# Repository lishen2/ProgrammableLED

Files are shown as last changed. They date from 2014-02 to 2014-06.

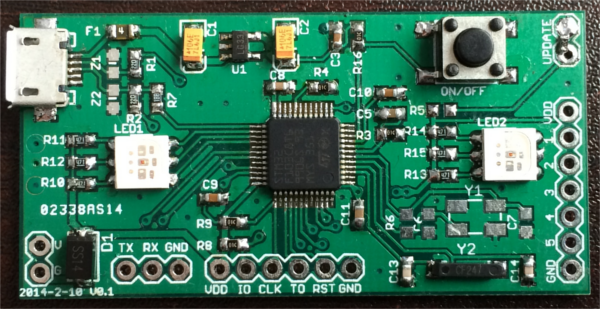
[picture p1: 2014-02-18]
images/IMG_0546.png

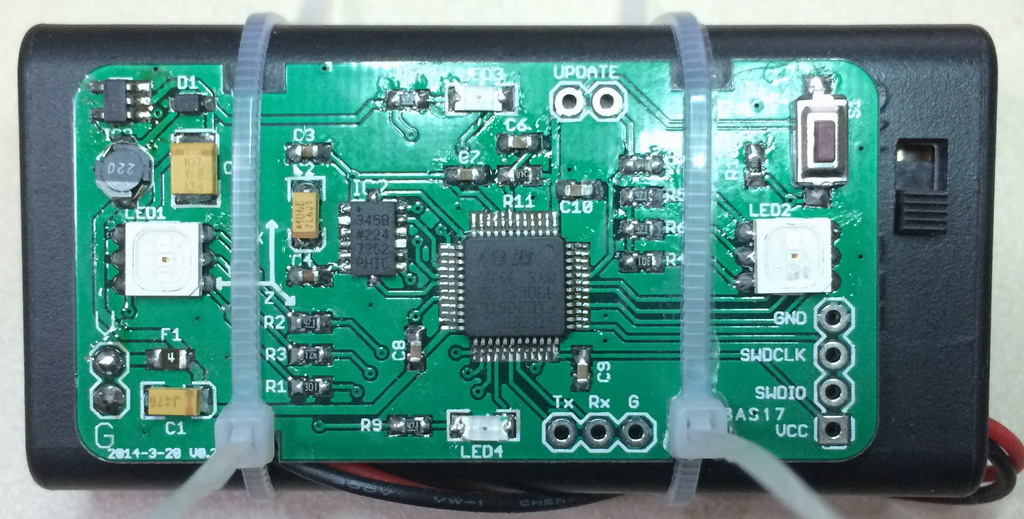
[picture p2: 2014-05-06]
images/finished2.JPG

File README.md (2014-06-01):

自动刹车灯
===============
自动刹车灯是一个小巧的电路板，在刹车减速时自动亮起。可以将其安装在自行车上，用于警示其他车辆和行人。自动刹车灯由电池供电并内置加速度传感器，因此无需额外连接其他线缆。使用两节5号电池时，设计待机时间为一年以上(待机功耗66微安)，基本可以实现永不关机，即装即忘。项目命名为“ProgrammableLED”是最初的初衷，现在已经简化为自动刹车等了，功能简化体验更优。


特性
--------
* 体积2.8cm * 5.5cm(PCB尺寸)。
* 自动识别减速刹车。
* 停车自动休眠，设计待机时间一年以上。
* 软硬件设计开源。

应用
-------
* 自行车灯，提高车辆夜间识别度，增强安全性。

硬件资源
--------
* STM32F103C8T处理器
* 两个全彩LED灯，两个红色LED（1206）
* 加速度传感器ADXL345
* 一个三线串口
* 一个三线SWD接口

当前进度
--------
20140217: 第一版PCB制作完成.                     
20140220: 编写代码，STM32的USB驱动示例代码很烂，作为程序员不忍直视。              
20140319: 放弃使用USB口，原因是USB驱动比较复杂一直没有调试成功。                  
20140329: 第二版PCB制作完成，放弃USB接口，增加加速度传感器ADXL234和升压电路（保证LED亮度一致）                    
20140410：还在编写软件，放弃编程功能，仅留下刹车灯功能。                   
20140506：基本功能正常，正在优化功耗。
20140515：耗降到66微安，正在调整对加速度数值的处理。
20140601：加速度传感器参数调整完毕，经过几周实测，效果还不错。

开发博客
--------
<http://blog.sina.com.cn/lgeek>

Automatic Break Light
===============
Automatic Break Light is a small circuit board, it can automatically light up when decelerate. It can installed on a bicycle to caution other bicycle,  vehicle and people. Automatic Break Light has an accelerate sensor on board, so it will work without additional sensor or wire. It use two AA battery as power supply, designed to work at least 12 month(Standby power consumption is 66 uA). You no longer need to manually shut it down, and you can forget it after install. The project name "ProgrammableLED" is the original idea, but now it has enolved into "Automatic Break Light". Fewer functions, better experience.

Design feature
--------------
* size 2.8cm * 5.5cm(PCB size).
* recognize decelerate.
* automatic sleep when stop, standby lifetime more than 12 month.
* open source on both software and hardware.

Application
-----------
* Bicycle light, improve identification at night.

Hardware
--------
* STM32F103C8T MCU
* 2 RGB LED, 2 red LED
* ADXL345 acceleration sensor
* 1 USART port
* 1 SWD

Current progress
---------------
20140217: Finished first PCB.                
20140220: Working on the code, STM32's USB Driver is horrible.            
20140319: Abandon USB port, too complicated.         
20140329: Finished second PCB, abandon USB port, add ADXL234 sensor, and boost circuit.           
20140410：Still working on software, just break light.            
20140506：Barely work, working on reduce power consumption.
20140515：Standby power consumption down to 66 mA, Adjusting processing logic about acceleration value.
20140601: Finish adjusting logic. After several weeks trail, it's basically good.

Development blog
---------------
<http://lsgeek.blogspot.com>

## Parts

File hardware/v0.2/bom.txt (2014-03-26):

Partlist exported from /Users/lishen/Documents/eagle/SmartLED/2.sch at 14-3-25 下午7:53

Part Value                         Device                        Package               Description                                 PROD_ID   VALUE     
C1   22uF                          10UF-16V-10%(TANT)            EIA3216               CAP-00811                                   CAP-00811 10uF      
C2   10uF                          10UF-16V-10%(TANT)            EIA3216               CAP-00811                                   CAP-00811 10uF      
C3   0.1u                          C-EUC0603K                    C0603K                CAPACITOR, European symbol                                      
C4   0.1u                          C-EUC0603K                    C0603K                CAPACITOR, European symbol                                      
C5   100uF                         47UF-TANT                     EIA3528               47uF Tantalum SMT                           CAP-08310 47uF      
C6   10u                           C-EUC0603K                    C0603K                CAPACITOR, European symbol                                      
C7   0.1u                          C-EUC0603K                    C0603K                CAPACITOR, European symbol                                      
C8   0.1u                          C-EUC0603K                    C0603K                CAPACITOR, European symbol                                      
C9   0.1u                          C-EUC0603K                    C0603K                CAPACITOR, European symbol                                      
C10  4.7u                          C-EUC0603K                    C0603K                CAPACITOR, European symbol                                      
D1   BAT20JFILM                    BAT20JFILM                    SOD-323               23V, 1A Schottky diode, SOD-323 package     DIO-11623 BAT20JFILM
F1   500ma                         L-EUL2012C                    L2012C                INDUCTOR, European symbol                                       
IC1  STM32F10XCXT6                 STM32F10XCXT6                 TQFP48                ST STM32F101/103 48pin LQFP                                     
IC2  ADXL345"                      ADXL345"                      ADXL3451:1            3-axis SPI/I2C 2/4/8/16g accelerometer                          
IC3                                BL8530-XX2_RN                 SOT23-5               PFC step-up DC boost                                            
JP1                                M03PTH                        1X03                  Header 3                                                        
JP2  M02PTH                        M02PTH                        1X02                  Standard 2-pin 0.1" header. Use with                            
JP3                                M04PTH                        1X04                  Header 4                                                        
JP4  M02PTH                        M02PTH                        1X02                  Standard 2-pin 0.1" header. Use with                            
L1   22uh                          INDUCTORVLF4012A              VLF4012A              Inductors                                                       
LED1 LED-TRICOLOR-5050NO_IC        LED-TRICOLOR-5050NO_IC        LED-TRICOLOR-5050                                                                     
LED2 LED-TRICOLOR-5050NO_IC        LED-TRICOLOR-5050NO_IC        LED-TRICOLOR-5050                                                                     
LED3                               LED1206                       LED-1206              LEDs                                                            
LED4                               LED1206                       LED-1206              LEDs                                                            
R1   270                           R-EU_R0603                    R0603                 RESISTOR, European symbol                                       
R2   270                           R-EU_R0603                    R0603                 RESISTOR, European symbol                                       
R3   270                           R-EU_R0603                    R0603                 RESISTOR, European symbol                                       
R4   270                           R-EU_R0603                    R0603                 RESISTOR, European symbol                                       
R5   270                           R-EU_R0603                    R0603                 RESISTOR, European symbol                                       
R6   270                           R-EU_R0603                    R0603                 RESISTOR, European symbol                                       
R7   10K                           R-EU_R0603                    R0603                 RESISTOR, European symbol                                       
R8   270                           R-EU_R0603                    R0603                 RESISTOR, European symbol                                       
R9   270                           R-EU_R0603                    R0603                 RESISTOR, European symbol                                       
R10  10K                           R-EU_R0603                    R0603                 RESISTOR, European symbol                                       
R11  10K                           R-EU_R0603                    R0603                 RESISTOR, European symbol                                       
S1   SWITCH-MOMENTARY-2-SMD-1101NE SWITCH-MOMENTARY-2-SMD-1101NE TACTILE-SWITCH-1101NE Various NO switches- pushbuttons, reed, etc

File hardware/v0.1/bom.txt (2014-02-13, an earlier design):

Partlist exported from C:/Documents and Settings/Administrator/eagle/SmartLED/1.sch at 2014-2-13 17:03:51

Part Value                   Device                  Package                       Description                                                                         PROD_ID    VALUE       
C1   10uF                    10UF-TANT               EIA3216                       10uF Tantalum SMT                                                                   CAP-00811  10uF        
C2   10uF                    10UF-TANT               EIA3216                       10uF Tantalum SMT                                                                   CAP-00811  10uF        
C3   0.1u                    C-EUC0603K              C0603K                        CAPACITOR, European symbol                                                                                 
C5   10u                     C-EUC0603K              C0603K                        CAPACITOR, European symbol                                                                                 
C6   20p                     C-EUC0603K              C0603K                        CAPACITOR, European symbol                                                                                 
C7   20p                     C-EUC0603K              C0603K                        CAPACITOR, European symbol                                                                                 
C8   0.1u                    C-EUC0603K              C0603K                        CAPACITOR, European symbol                                                                                 
C9   0.1u                    C-EUC0603K              C0603K                        CAPACITOR, European symbol                                                                                 
C10  0.1u                    C-EUC0603K              C0603K                        CAPACITOR, European symbol                                                                                 
C11  4.7u                    C-EUC0603K              C0603K                        CAPACITOR, European symbol                                                                                 
C13  20p                     C-EUC0603K              C0603K                        CAPACITOR, European symbol                                                                                 
C14  20p                     C-EUC0603K              C0603K                        CAPACITOR, European symbol                                                                                 
D1   MBRA140                 MBRA140                 SMA-DIODE                     40V, 1A Schottky rectifier                                                          DIO-08053              
F1   500ma                   L-EUL2012C              L2012C                        INDUCTOR, European symbol                                                                                  
IC2  STM32F10XCXT6           STM32F10XCXT6           TQFP48                        ST STM32F101/103 48pin LQFP                                                                                
JP1  USB-MICROB              USB-MICROB              USB-MICROB                    USB Connectors                                                                      CONN-09505             
JP2  M02PTH                  M02PTH                  1X02                          Standard 2-pin 0.1" header. Use with                                                                       
JP3                          M06SIP                  1X06                          Header 6                                                                                                   
JP4                          M03PTH                  1X03                          Header 3                                                                                                   
JP5  M02PTH                  M02PTH                  1X02                          Standard 2-pin 0.1" header. Use with                                                                       
JP6                          M07                     1X07                          Header 7                                                                                                   
LED1 LED-TRICOLOR-5050NO_IC  LED-TRICOLOR-5050NO_IC  LED-TRICOLOR-5050                                                                                                                        
LED2 LED-TRICOLOR-5050NO_IC  LED-TRICOLOR-5050NO_IC  LED-TRICOLOR-5050                                                                                                                        
R1   22R                     R-EU_R0603              R0603                         RESISTOR, European symbol                                                                                  
R2   22R                     R-EU_R0603              R0603                         RESISTOR, European symbol                                                                                  
R3   10K                     R-EU_R0603              R0603                         RESISTOR, European symbol                                                                                  
R4   10K                     R-EU_R0603              R0603                         RESISTOR, European symbol                                                                                  
R5   10K                     R-EU_R0603              R0603                         RESISTOR, European symbol                                                                                  
R6   1M                      R-EU_R0603              R0603                         RESISTOR, European symbol                                                                                  
R7   1.5K                    R-EU_R0603              R0603                         RESISTOR, European symbol                                                                                  
R8   10K                     R-EU_R0603              R0603                         RESISTOR, European symbol                                                                                  
R9   10K                     R-EU_R0603              R0603                         RESISTOR, European symbol                                                                                  
R10  470R                    R-EU_R0603              R0603                         RESISTOR, European symbol                                                                                  
R11  470R                    R-EU_R0603              R0603                         RESISTOR, European symbol                                                                                  
R12  470R                    R-EU_R0603              R0603                         RESISTOR, European symbol                                                                                  
R13  470R                    R-EU_R0603              R0603                         RESISTOR, European symbol                                                                                  
R14  470R                    R-EU_R0603              R0603                         RESISTOR, European symbol                                                                                  
R15  470R                    R-EU_R0603              R0603                         RESISTOR, European symbol                                                                                  
R16  10K                     R-EU_R0603              R0603                         RESISTOR, European symbol                                                                                  
S1   SWITCH-MOMENTARY-2SMD-4 SWITCH-MOMENTARY-2SMD-4 TACTILE_SWITCH_TALL           Various NO switches- pushbuttons, reed, etc                                                                
U1   MIC5219 3.3V            V_REG_MIC52193.3V       SOT23-5                       V_REG MIC5219                                                                       VREG-09872 MIC5219 3.3V
Y1   8MHZ                    CRYSTAL5X3              CRYSTAL-SMD-5X3               Various standard crystals. Proven footprints. Spark Fun Electronics SKU : COM-00534                        
Y2   32768                   CRYSTALEPSONMC146       CRYSTAL-32KHZ-SMD_EPSON_MC146 Various standard crystals. Proven footprints. Spark Fun Electronics SKU : COM-00534                        
Z1                           VARISTOR-0603           0603-RES                      Varistor                                                                                                   
Z2                           VARISTOR-0603           0603-RES                      Varistor

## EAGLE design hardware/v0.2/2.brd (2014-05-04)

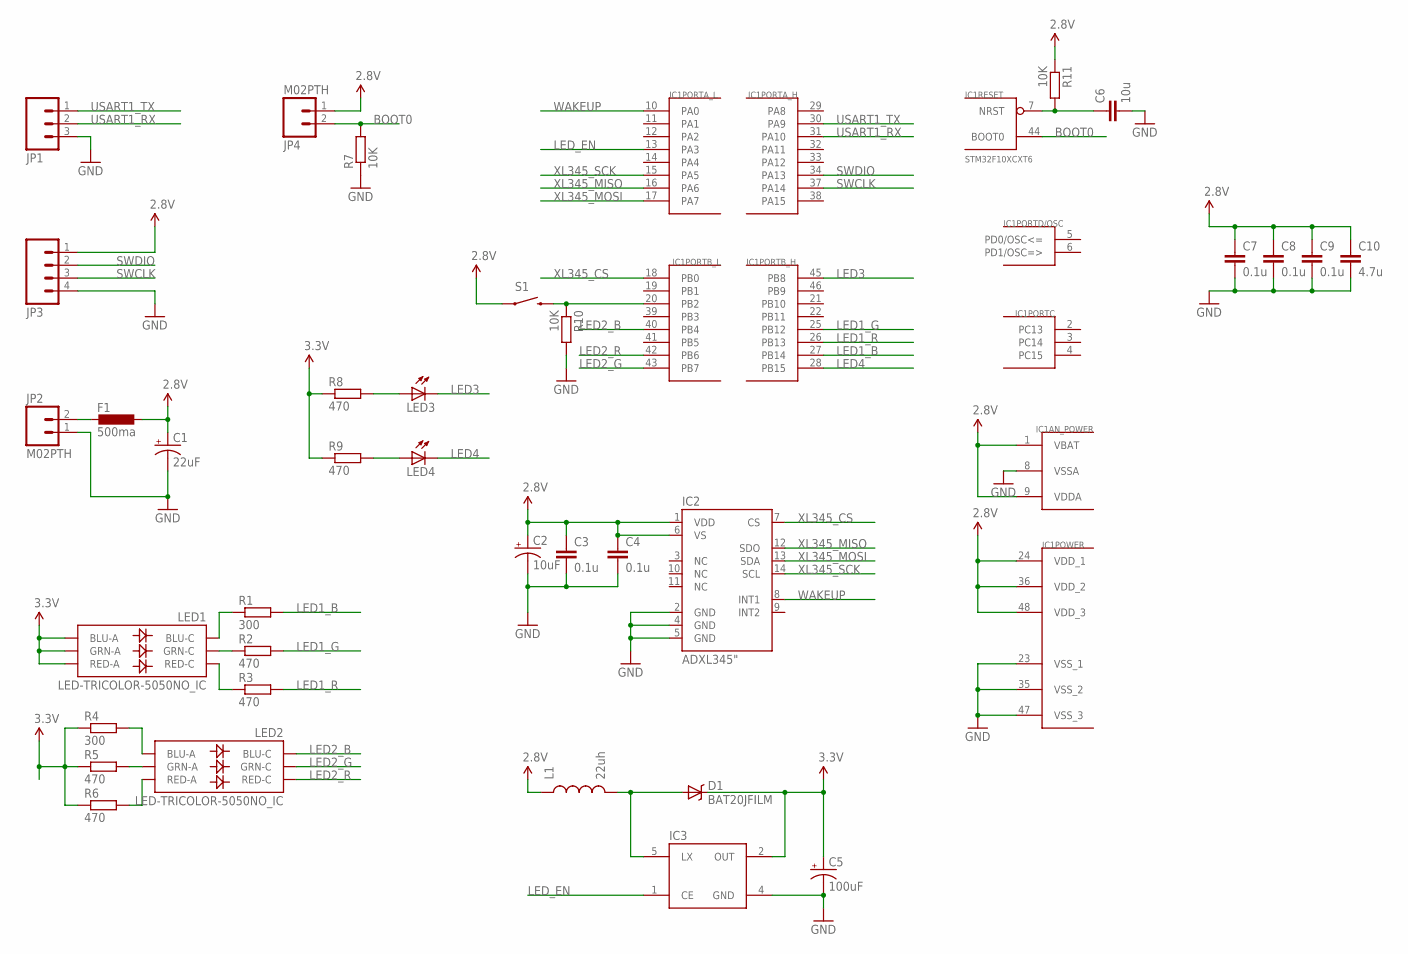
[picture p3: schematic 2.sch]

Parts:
C1: 22uF; EIA3216
C2: 10uF; EIA3216
C3, C4, C7, C8, C9: 0.1u; C0603K
C5: 100uF; EIA3528
C6: 10u; C0603K
C10: 4.7u; C0603K
D1: BAT20JFILM; SOD-323
F1: 500ma; L2012C
IC1: STM32F10XCXT6; TQFP48
IC2: ADXL345"; ADXL3451:1
IC3: BL8530-XX2_RN; SOT23-5
JP1: M03PTH; 1X03
JP2, JP4: M02PTH; 1X02
JP3: M04PTH; 1X04
L1: 22uh; VLF4012A
LED1, LED2: LED-TRICOLOR-5050NO_IC; LED-TRICOLOR-5050
LED3, LED4: LED1206; LED-1206
R1, R4: 300; R0603
R2, R3, R5, R6, R8, R9: 470; R0603
R7, R10, R11: 10K; R0603
S1: SWITCH-MOMENTARY-2-SMD-1101NE; TACTILE-SWITCH-1101NE

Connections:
2.8V: C1.A (+), C2.A (+), C3.1, C4.1, C7.1, C8.1, C9.1, C10.1, F1.1, IC1.1 (VBAT), IC1.9 (VDDA), IC1.24 (VDD_1), IC1.36 (VDD_2), IC1.48 (VDD_3), IC2.1 (VDD), IC2.6 (VS), JP3.1, JP4.1, L1.P$1 (1), R11.1, S1.P$1 (1)
3.3V: C5.A (+), D1.1 (C), IC3.2 (OUT), LED1.1 (GRN-A), LED1.2 (RED-A), LED1.3 (BLU-A), R4.1, R5.1, R6.1, R8.1, R9.1
BOOT0: IC1.44 (BOOT0), JP4.2, R7.2
GND: C1.C (-), C2.C (-), C3.2, C4.2, C5.C (-), C6.2, C7.2, C8.2, C9.2, C10.2, IC1.8 (VSSA), IC1.23 (VSS_1), IC1.35 (VSS_2), IC1.47 (VSS_3), IC2.2 (GND), IC2.4 (GND), IC2.5 (GND), IC3.4 (GND), JP1.3, JP2.1, JP3.4, R7.1, R10.2
LED1_B: IC1.27 (PB14), R1.2
LED1_G: IC1.25 (PB12), R2.2
LED1_R: IC1.26 (PB13), R3.2
LED2_B: IC1.40 (PB4), LED2.4 (BLU-C)
LED2_G: IC1.43 (PB7), LED2.6 (GRN-C)
LED2_R: IC1.42 (PB6), LED2.5 (RED-C)
LED3: IC1.45 (PB8), LED3.C
LED4: IC1.28 (PB15), LED4.C
LED_EN: IC1.13 (PA3), IC3.1 (CE)
unnamed: F1.2, JP2.2
unnamed: IC1.20 (PB2), R10.1, S1.P$2 (2)
unnamed: LED4.A, R9.2
unnamed: LED3.A, R8.2
unnamed: LED2.3 (BLU-A), R4.2
unnamed: LED1.6 (GRN-C), R2.1
unnamed: LED2.2 (RED-A), R6.2
unnamed: LED1.4 (BLU-C), R1.1
unnamed: LED2.1 (GRN-A), R5.2
unnamed: LED1.5 (RED-C), R3.1
unnamed: D1.2 (A), IC3.5 (LX), L1.P$2 (2)
RESET: C6.1, IC1.7 (NRST), R11.2
SWCLK: IC1.37 (PA14), JP3.3
SWDIO: IC1.34 (PA13), JP3.2
USART1_RX: IC1.31 (PA10), JP1.2
USART1_TX: IC1.30 (PA9), JP1.1
WAKEUP: IC1.10 (PA0), IC2.8 (INT1)
XL345_CS: IC1.18 (PB0), IC2.7 (CS)
XL345_MISO: IC1.16 (PA6), IC2.12 (SDO)
XL345_MOSI: IC1.17 (PA7), IC2.13 (SDA)
XL345_SCK: IC1.15 (PA5), IC2.14 (SCL)

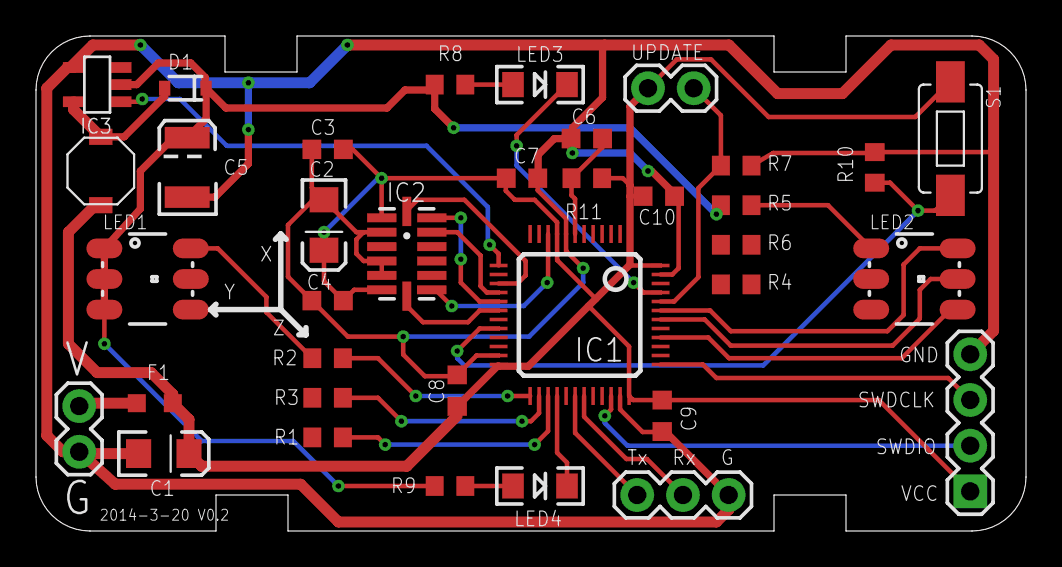
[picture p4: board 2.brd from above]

Board: 2 copper layers, 55.0 x 27.5 mm, 36 parts (0 on the bottom side), 34 nets.

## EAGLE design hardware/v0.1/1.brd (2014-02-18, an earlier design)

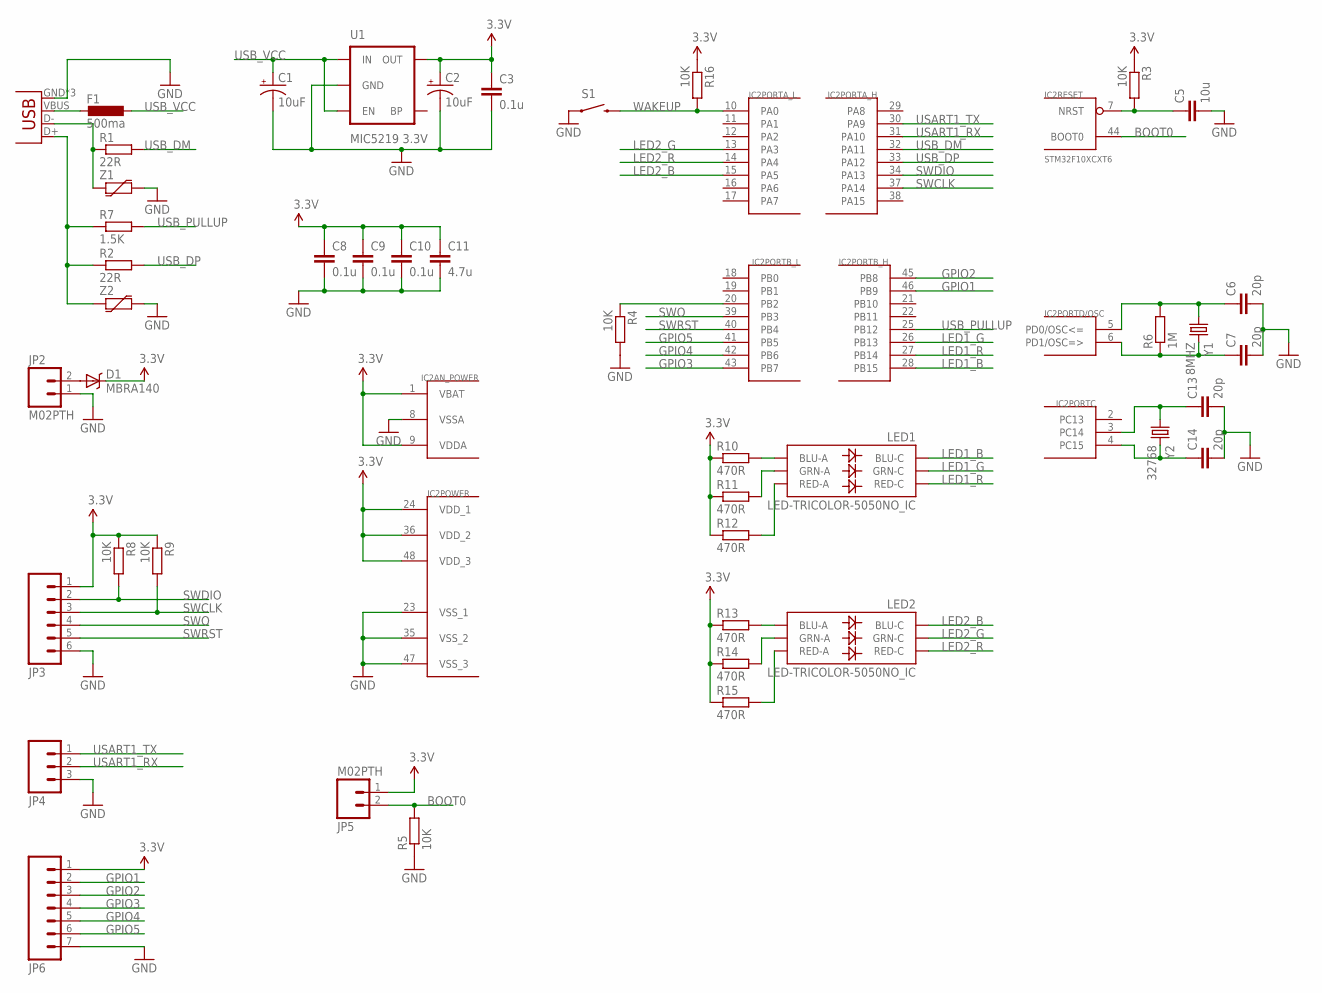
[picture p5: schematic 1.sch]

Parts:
C1, C2: 10uF; EIA3216
C3, C8, C9, C10: 0.1u; C0603K
C5: 10u; C0603K
C6, C7, C13, C14: 20p; C0603K
C11: 4.7u; C0603K
D1: MBRA140; SMA-DIODE
F1: 500ma; L2012C
IC2: STM32F10XCXT6; TQFP48
JP1: USB-MICROB
JP2, JP5: M02PTH; 1X02
JP3: M06SIP; 1X06
JP4: M03PTH; 1X03
JP6: M07; 1X07
LED1, LED2: LED-TRICOLOR-5050NO_IC; LED-TRICOLOR-5050
R1, R2: 22R; R0603
R3, R4, R5, R8, R9, R16: 10K; R0603
R6: 1M; R0603
R7: 1.5K; R0603
R10, R11, R12, R13, R14, R15: 470R; R0603
S1: SWITCH-MOMENTARY-2SMD-4; TACTILE_SWITCH_TALL
U1: MIC5219 3.3V; SOT23-5
Y1: 8MHZ; CRYSTAL-SMD-5X3
Y2: 32768; CRYSTAL-32KHZ-SMD_EPSON_MC146
Z1, Z2: VARISTOR-0603; 0603-RES

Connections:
3.3V: C2.A (+), C3.1, C8.1, C9.1, C10.1, C11.1, D1.C, IC2.1 (VBAT), IC2.9 (VDDA), IC2.24 (VDD_1), IC2.36 (VDD_2), IC2.48 (VDD_3), JP3.1, JP5.1, JP6.1, R3.1, R8.1, R9.1, R10.1, R11.1, R12.1, R13.1, R14.1, R15.1, R16.1, U1.5 (OUT)
BOOT0: IC2.44 (BOOT0), JP5.2, R5.2
GND: C1.C (-), C2.C (-), C3.2, C5.2, C6.2, C7.2, C8.2, C9.2, C10.2, C11.2, C13.2, C14.2, IC2.8 (VSSA), IC2.23 (VSS_1), IC2.35 (VSS_2), IC2.47 (VSS_3), JP1.GND, JP1.MT1 (GND), JP1.MT2 (GND), JP2.1, JP3.6, JP4.3, JP6.7, R4.2, R5.1, S1.A2 (1), U1.2 (GND), Z1.2, Z2.2
GPIO1: IC2.46 (PB9), JP6.2
GPIO2: IC2.45 (PB8), JP6.3
GPIO3: IC2.43 (PB7), JP6.4
GPIO4: IC2.42 (PB6), JP6.5
GPIO5: IC2.41 (PB5), JP6.6
LED1_B: IC2.28 (PB15), LED1.4 (BLU-C)
LED1_G: IC2.26 (PB13), LED1.6 (GRN-C)
LED1_R: IC2.27 (PB14), LED1.5 (RED-C)
LED2_B: IC2.15 (PA5), LED2.4 (BLU-C)
LED2_G: IC2.13 (PA3), LED2.6 (GRN-C)
LED2_R: IC2.14 (PA4), LED2.5 (RED-C)
unnamed: D1.A, JP2.2
unnamed: IC2.20 (PB2), R4.1
unnamed: JP1.D-, R1.1, Z1.1
unnamed: JP1.D+, R2.1, R7.1, Z2.1
unnamed: C6.1, IC2.5 (PD0/OSC<=), R6.2, Y1.1
unnamed: C7.1, IC2.6 (PD1/OSC=>), R6.1, Y1.3 (2)
unnamed: LED1.3 (BLU-A), R10.2
unnamed: F1.2, JP1.VBUS
unnamed: LED1.1 (GRN-A), R11.2
unnamed: LED1.2 (RED-A), R12.2
unnamed: LED2.3 (BLU-A), R13.2
unnamed: LED2.1 (GRN-A), R14.2
unnamed: LED2.2 (RED-A), R15.2
unnamed: C13.1, IC2.3 (PC14), Y2.P$2 (1)
unnamed: C14.1, IC2.4 (PC15), Y2.P$1 (2)
RESET: C5.1, IC2.7 (NRST), R3.2
SWCLK: IC2.37 (PA14), JP3.3, R9.2
SWDIO: IC2.34 (PA13), JP3.2, R8.2
SWO: IC2.39 (PB3), JP3.4
SWRST: IC2.40 (PB4), JP3.5
USART1_RX: IC2.31 (PA10), JP4.2
USART1_TX: IC2.30 (PA9), JP4.1
USB_DM: IC2.32 (PA11), R1.2
USB_DP: IC2.33 (PA12), R2.2
USB_PULLUP: IC2.25 (PB12), R7.2
USB_VCC: C1.A (+), F1.1, U1.1 (IN), U1.3 (EN)
WAKEUP: IC2.10 (PA0), R16.2, S1.B2 (2)

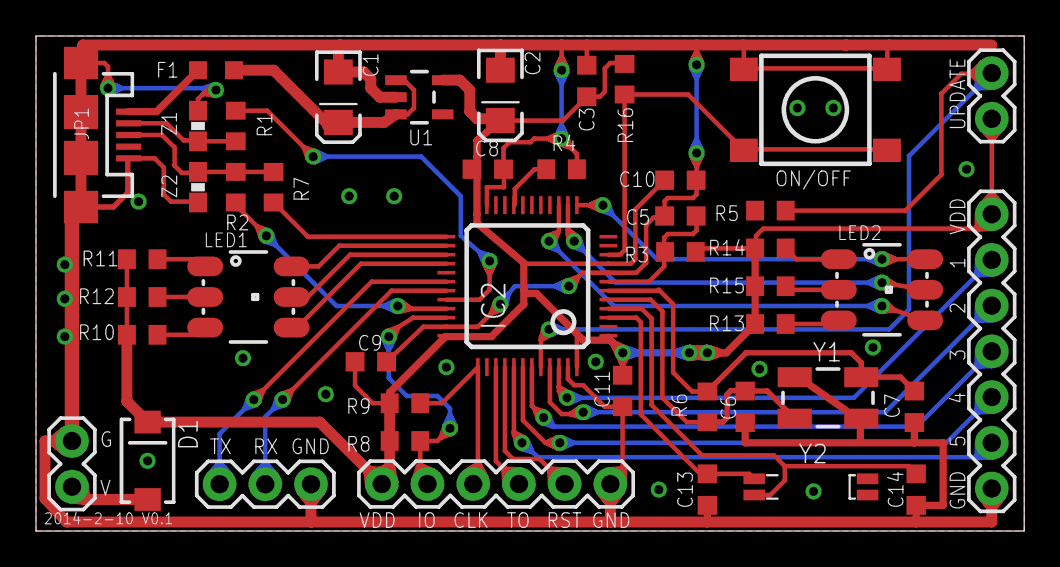
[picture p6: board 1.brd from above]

Board: 2 copper layers, 54.9 x 27.5 mm, 45 parts (0 on the bottom side), 41 nets.

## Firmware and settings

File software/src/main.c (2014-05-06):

#include "stm32f10x.h"
#include "utils.h"
#include "acc_sensor.h"
#include "display_state.h"
#include "button.h"
#include "led.h"
#include "xl345.h"
#include "power.h"

int main()
{	
    PWR_SetUnusedPin();
	HW_CommonInit();
  	LED_Init();
	HW_InitSysTick();  
	ACC_Init();  
    STATE_Init();
	BTN_Init();

	while(1){
        PWR_EnterSLEEPMode();
	}
}

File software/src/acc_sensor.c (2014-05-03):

#include "stm32f10x.h"
#include "utils.h"
#include "acc_sensor.h"
#include "xl345.h"

/* accelerate sensor interrupt pin */
#define ACC_INT_PIN         GPIO_Pin_0
#define ACC_INT_PORT        GPIOA
#define ACC_INT_RCC         RCC_APB2Periph_GPIOA
#define ACC_INT_PORTSOURCE  GPIO_PortSourceGPIOA
#define ACC_INT_PINSOURCE   GPIO_PinSource0
#define ACC_INT_IRQ         EXTI0_IRQn
#define ACC_INT_IRQROUTINE  EXTI0_IRQHandler
#define ACC_INT_EXTILINE    EXTI_Line0

static ACC_IRQHandler g_handler = NULL;

static void _initInterrupt(void)
{
	GPIO_InitTypeDef GPIO_InitStructure;
	EXTI_InitTypeDef EXTI_InitStructure;
	NVIC_InitTypeDef NVIC_InitStructure;

	RCC_APB2PeriphClockCmd(ACC_INT_RCC, ENABLE);

	GPIO_InitStructure.GPIO_Pin = ACC_INT_PIN;
	GPIO_InitStructure.GPIO_Speed = GPIO_Speed_50MHz;
	GPIO_InitStructure.GPIO_Mode = GPIO_Mode_IPD;
	GPIO_Init(ACC_INT_PORT, &GPIO_InitStructure);	
	GPIO_EXTILineConfig(ACC_INT_PORTSOURCE, ACC_INT_PINSOURCE); 

    NVIC_InitStructure.NVIC_IRQChannel = ACC_INT_IRQ;
	NVIC_InitStructure.NVIC_IRQChannelPreemptionPriority = 1;
    NVIC_InitStructure.NVIC_IRQChannelSubPriority = 0;
    NVIC_InitStructure.NVIC_IRQChannelCmd = ENABLE;
    NVIC_Init(&NVIC_InitStructure);

	EXTI_InitStructure.EXTI_Line = ACC_INT_EXTILINE;
	EXTI_InitStructure.EXTI_Mode = EXTI_Mode_Interrupt;
	EXTI_InitStructure.EXTI_Trigger = EXTI_Trigger_Rising; 
	EXTI_InitStructure.EXTI_LineCmd = ENABLE;
	EXTI_Init(&EXTI_InitStructure);

	return;
}

void ACC_Init(void)
{
    XL345_Init();
	_initInterrupt();

    return;
}

/* read accelerate from sensor queue */
void ACC_ReadAcc(u8 fifoLen, s16 *X, s16 *Y, s16*Z)
{
	u8 buf[6];
    u16 x, y, z;
    s32 avX, avY, avZ;
    u8 i;

    avX = 0;
    avY = 0;
    avZ = 0;
    
    for (i = 0; i < fifoLen; ++i){
        XL345_Read(sizeof(buf), XL345_DATAX0, buf);
        x = (buf[1] << 8 | buf[0]);
        y = (buf[3] << 8 | buf[2]);        
        z = (buf[5] << 8 | buf[4]);             

        avX += (s32)(s16)x;
        avY += (s32)(s16)y;
        avZ += (s32)(s16)z;        
    }

	*X = (s16)(avX/fifoLen);
	*Y = (s16)(avY/fifoLen);
	*Z = (s16)(avZ/fifoLen);

    return;
}

void ACC_SetIRQHandler(ACC_IRQHandler handler)
{
	g_handler = handler;

	return;
}

void ACC_INT_IRQROUTINE(void)
{
	u8 irq;

	if (SET == EXTI_GetITStatus(ACC_INT_EXTILINE)){
		EXTI_ClearITPendingBit(ACC_INT_EXTILINE);  

	    /* read int source */
		XL345_Read(1, XL345_INT_SOURCE, &irq);

		/* call handler */
		if (NULL != g_handler){
			g_handler(irq);
		}      
	}
	
	return;	
}

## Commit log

2014-02-13 update readme, commit pcb design
    [1.brd, 1.sch]
2014-02-18 Update readme.md, fix a minor bug on PCB
    [1.brd, 1.sch]
2014-02-20 更新进度
2014-02-21 update usb driver
2014-02-24 continue development usb driver
2014-03-02 writing usb driver
2014-03-16 add version 2 pcb desgin
    [2.brd, 2.sch]
2014-03-17 modify pcb design
    [2.brd, 2.sch]
2014-03-18 test led pwm alg
2014-03-19 Updated V2 PCB design
    [2.brd, 2.sch]
2014-03-20 update PCB design
    [2.brd, 2.sch]
2014-03-20 nearly finish PCB design
    [2.brd, 2.sch]
2014-03-24 finish version 0.2 pcb design
    [2.brd, 2.sch]
2014-05-04 update schematic for clearance
    [2.brd, 2.sch]
2014-05-05 reduce standby power
2014-05-05 improve power consumion
    [2.sch]
2014-05-06 reduce power consumption
2014-05-06 achieve 66 uA standby power consumption
2014-05-11 fix a bug: device won't sleep
    [led.c]
2014-05-16 修改readme;升级加速度数据处理逻辑
2014-05-20 update acc sensor parameter

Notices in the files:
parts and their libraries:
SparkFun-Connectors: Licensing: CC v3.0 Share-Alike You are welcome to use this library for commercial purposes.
